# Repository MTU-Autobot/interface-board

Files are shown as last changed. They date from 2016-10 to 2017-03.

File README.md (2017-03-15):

# interface-board


Interface board for MTU's IGVC robot. The board connects to an RC controller, wheel encoders, motor controllers, and status lights and is controlled over USB. The microcontroller is a MK20DX256 running a Teensy 3.2 bootloader for easy programming. Main power conversion is handled by a TPS62143 buck converter and can handle up to 17 volts in for compatibility with 12 volt systems.

To interface with the board you need to setup the udev rules found [here](https://www.pjrc.com/teensy/loader_linux.html)

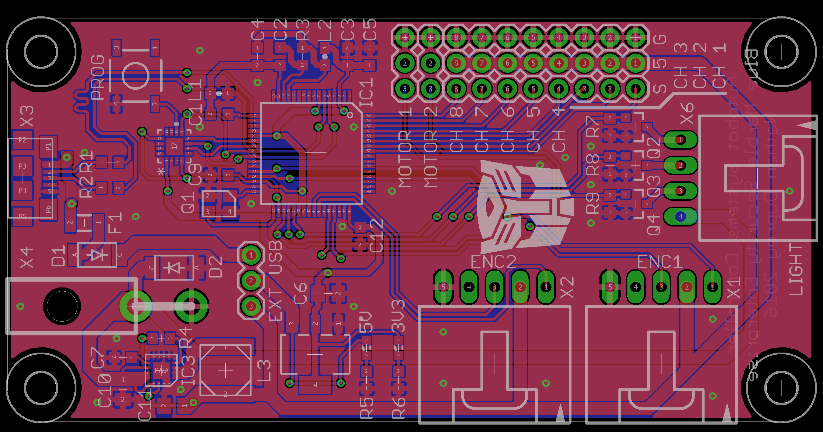
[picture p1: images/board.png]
pcb layout

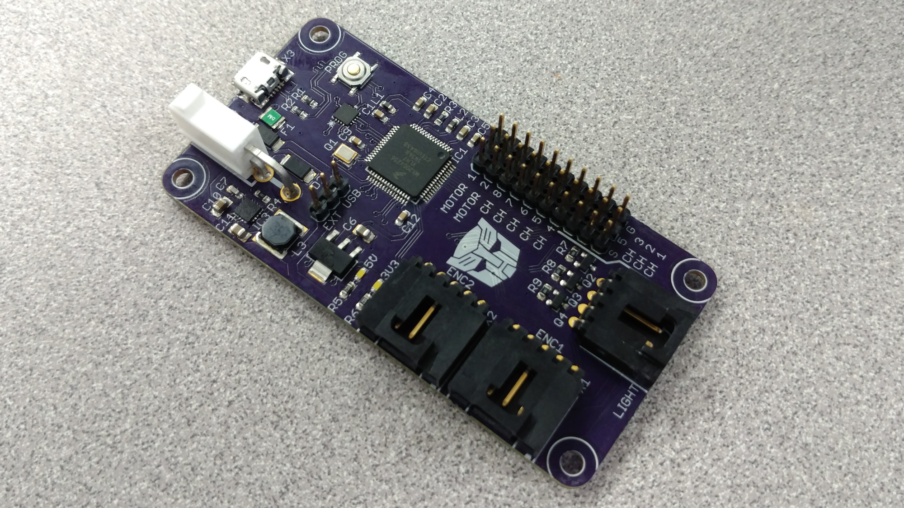
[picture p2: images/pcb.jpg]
assembled board


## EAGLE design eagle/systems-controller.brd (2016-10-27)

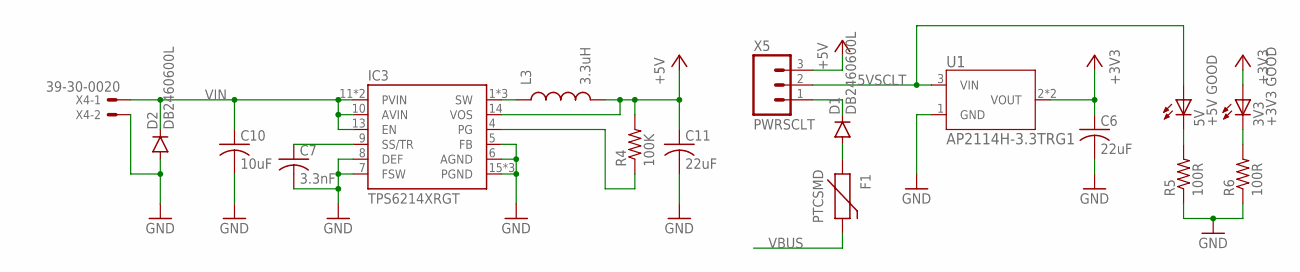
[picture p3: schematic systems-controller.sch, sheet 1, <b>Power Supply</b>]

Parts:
3V3: +3V3 GOOD; SML0603
5V: +5V GOOD; SML0603
C6, C11: 22uF; C0805K
C7: 3.3nF; C0603K
C10: 10uF; C0805K
D1, D2: DB2460600L; SOD-128
F1: PTCSMD; PTC-1206
IC3: TPS6214XRGT; 16-VQFN
L3: 3.3uH; SRN5020
R4: 100K; R0603
R5, R6: 100R; R0603
U1: AP2114H-3.3TRG1; SOT-223
X4: 39-30-0020
X5: PWRSCLT; 1X03

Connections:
5VSCLT: 5V.A, U1.3 (VIN), X5.2
+3V3: 3V3.A, C6.1, U1.2 (VOUT), U1.4 (VOUT); also elsewhere on the board
+5V: C11.1, IC3.14 (VOS), L3.2, R4.2, X5.3; also elsewhere on the board
GND: C6.2, C7.2, C10.2, C11.2, D2.A, IC3.5 (FB), IC3.6 (AGND), IC3.7 (FSW), IC3.8 (DEF), IC3.15 (PGND), IC3.16 (PGND), IC3.PAD (PGND), R5.1, R6.1, U1.1 (GND), X4.2; also elsewhere on the board
unnamed: IC3.4 (PG), R4.1
unnamed: C7.1, IC3.9 (SS/TR)
unnamed: D1.C, X5.1
unnamed: IC3.1 (SW), IC3.2 (SW), IC3.3 (SW), L3.1
unnamed: D1.A, F1.1
unnamed: 5V.C, R5.2
unnamed: 3V3.C, R6.2
VBUS: F1.2; also elsewhere on the board
VIN: C10.1, D2.C, IC3.10 (AVIN), IC3.11 (PVIN), IC3.12 (PVIN), IC3.13 (EN), X4.1; also elsewhere on the board

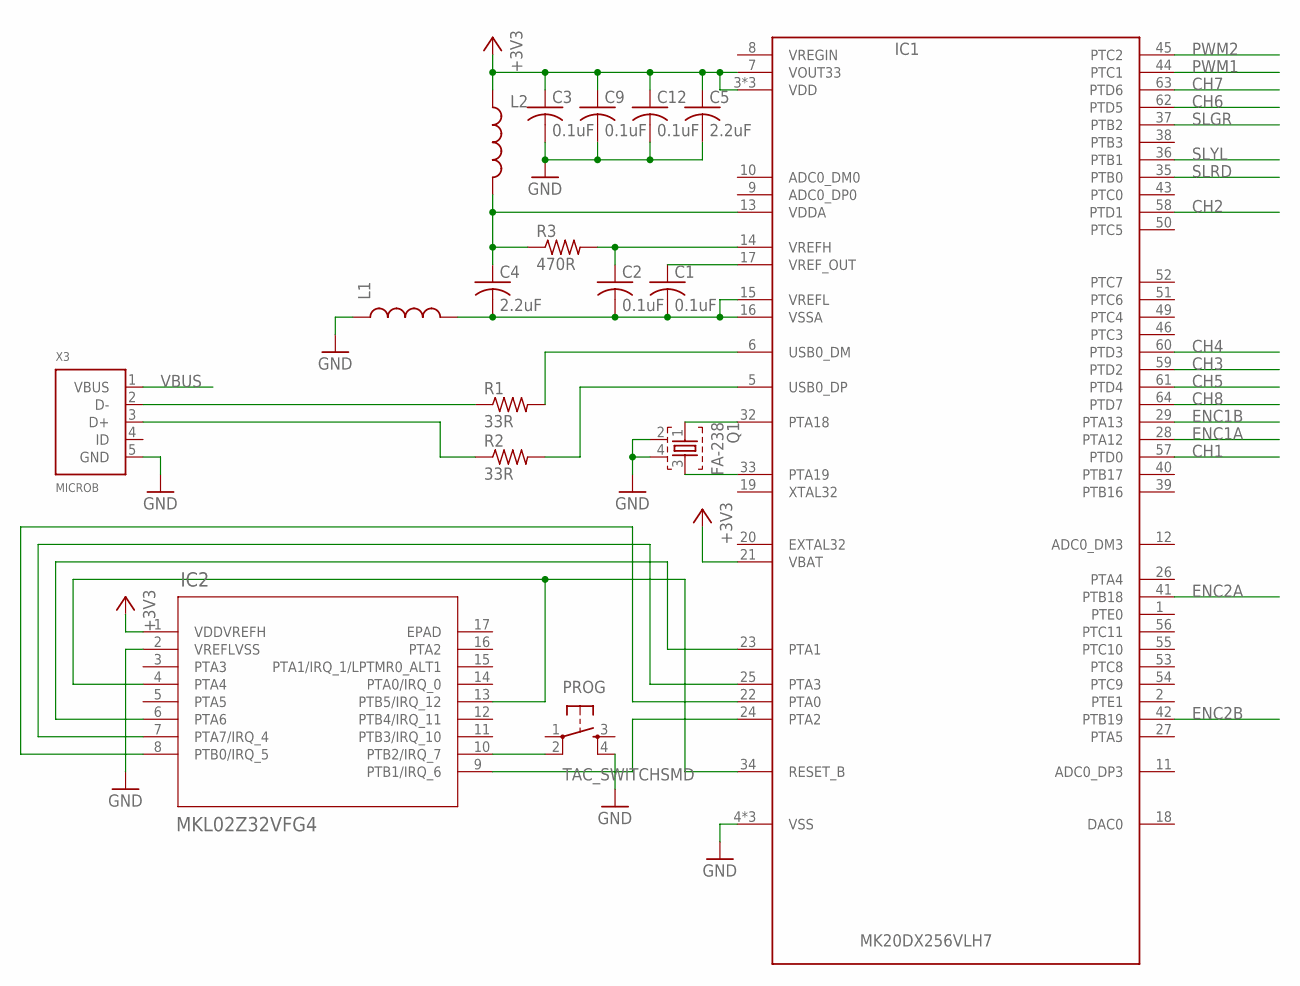
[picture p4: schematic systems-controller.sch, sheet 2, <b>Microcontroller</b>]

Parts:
C1, C2, C3, C9, C12: 0.1uF; C0603K
C4, C5: 2.2uF; C0603K
IC1: MK20DX256VLH7
IC2: MKL02Z32VFG4; QFN-16_3X3X0.65
L1, L2: INDUCTOR30OHM,1.8A; 0603
PROG: TAC_SWITCHSMD; TACTILE-SWITCH-SMD
Q1: FA-238
R1, R2: 33R; R0603
R3: 470R; R0603
X3: MICROB; 10118192

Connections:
+3V3: C3.1, C5.1, C9.1, C12.1, IC1.3 (VDD), IC1.7 (VOUT33), IC1.21 (VBAT), IC1.30 (VDD), IC1.48 (VDD), IC2.1 (VDDVREFH), L2.1; also elsewhere on the board
CH1: IC1.57 (PTD0); also elsewhere on the board
CH2: IC1.58 (PTD1); also elsewhere on the board
CH3: IC1.59 (PTD2); also elsewhere on the board
CH4: IC1.60 (PTD3); also elsewhere on the board
CH5: IC1.61 (PTD4); also elsewhere on the board
CH6: IC1.62 (PTD5); also elsewhere on the board
CH7: IC1.63 (PTD6); also elsewhere on the board
CH8: IC1.64 (PTD7); also elsewhere on the board
ENC1A: IC1.28 (PTA12); also elsewhere on the board
ENC1B: IC1.29 (PTA13); also elsewhere on the board
ENC2A: IC1.41 (PTB18); also elsewhere on the board
ENC2B: IC1.42 (PTB19); also elsewhere on the board
GND: C3.2, C5.2, C9.2, C12.2, IC1.4 (VSS), IC1.31 (VSS), IC1.47 (VSS), IC2.2 (VREFLVSS), L1.1, PROG.4, Q1.2, Q1.4, X3.5 (GND); also elsewhere on the board
unnamed: IC1.25 (PTA3), IC2.7 (PTA7/IRQ_4)
unnamed: IC1.22 (PTA0), IC2.8 (PTB0/IRQ_5)
unnamed: IC1.24 (PTA2), IC2.9 (PTB1/IRQ_6)
unnamed: IC1.23 (PTA1), IC2.6 (PTA6)
unnamed: IC1.34 (RESET_B), IC2.4 (PTA4), IC2.13 (PTB5/IRQ_12)
unnamed: R1.1, X3.2 (D-)
unnamed: IC1.6 (USB0_DM), R1.2
unnamed: R2.1, X3.3 (D+)
unnamed: IC1.5 (USB0_DP), R2.2
unnamed: IC1.32 (PTA18), Q1.1
unnamed: IC1.33 (PTA19), Q1.3
unnamed: C1.2, C2.2, C4.2, IC1.15 (VREFL), IC1.16 (VSSA), L1.2
unnamed: C1.1, IC1.17 (VREF_OUT)
unnamed: C2.1, IC1.14 (VREFH), R3.2
unnamed: C4.1, IC1.13 (VDDA), L2.2, R3.1
unnamed: IC2.10 (PTB2/IRQ_7), PROG.2
PWM1: IC1.44 (PTC1); also elsewhere on the board
PWM2: IC1.45 (PTC2); also elsewhere on the board
SLGR: IC1.37 (PTB2); also elsewhere on the board
SLRD: IC1.35 (PTB0); also elsewhere on the board
SLYL: IC1.36 (PTB1); also elsewhere on the board
VBUS: X3.1 (VBUS); also elsewhere on the board

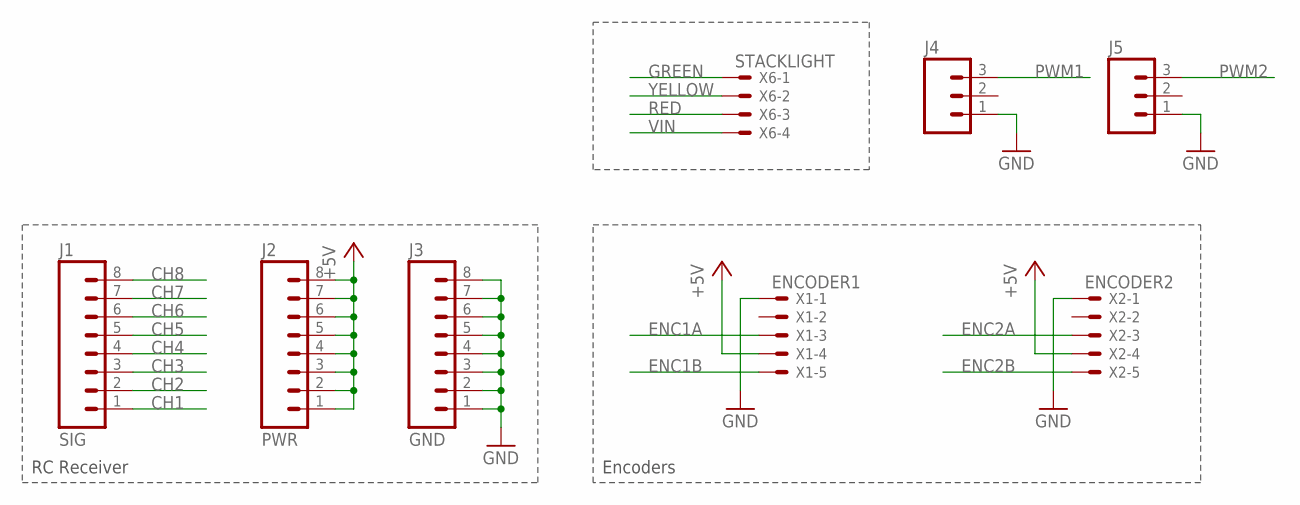
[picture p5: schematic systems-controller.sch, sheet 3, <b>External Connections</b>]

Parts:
J1: SIG; 1X08_ROUND
J2: PWR; 1X08_ROUND
J3: GND; 1X08_ROUND
J4, J5: M03PTH; 1X03
X1: ENCODER1; 70553-05
X2: ENCODER2; 70553-05
X6: STACKLIGHT; 70553-04

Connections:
+5V: J2.1, J2.2, J2.3, J2.4, J2.5, J2.6, J2.7, J2.8, X1.4, X2.4; also elsewhere on the board
CH1: J1.1; also elsewhere on the board
CH2: J1.2; also elsewhere on the board
CH3: J1.3; also elsewhere on the board
CH4: J1.4; also elsewhere on the board
CH5: J1.5; also elsewhere on the board
CH6: J1.6; also elsewhere on the board
CH7: J1.7; also elsewhere on the board
CH8: J1.8; also elsewhere on the board
ENC1A: X1.3; also elsewhere on the board
ENC1B: X1.5; also elsewhere on the board
ENC2A: X2.3; also elsewhere on the board
ENC2B: X2.5; also elsewhere on the board
GND: J3.1, J3.2, J3.3, J3.4, J3.5, J3.6, J3.7, J3.8, J4.1, J5.1, X1.1, X2.1; also elsewhere on the board
GREEN: X6.1; also elsewhere on the board
PWM1: J4.3; also elsewhere on the board
PWM2: J5.3; also elsewhere on the board
RED: X6.3; also elsewhere on the board
VIN: X6.4; also elsewhere on the board
YELLOW: X6.2; also elsewhere on the board

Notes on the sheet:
RC Receiver
Encoders

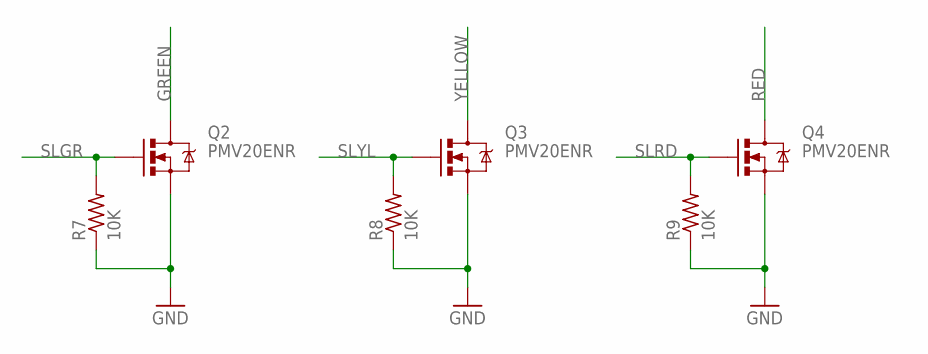
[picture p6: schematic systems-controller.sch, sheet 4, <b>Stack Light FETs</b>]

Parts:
Q2, Q3, Q4: PMV20ENR; SOT23-3
R7, R8, R9: 10K; R0603

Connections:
GND: Q2.2 (S), Q3.2 (S), Q4.2 (S), R7.1, R8.1, R9.1; also elsewhere on the board
GREEN: Q2.3 (D); also elsewhere on the board
RED: Q4.3 (D); also elsewhere on the board
SLGR: Q2.1 (G), R7.2; also elsewhere on the board
SLRD: Q4.1 (G), R9.2; also elsewhere on the board
SLYL: Q3.1 (G), R8.2; also elsewhere on the board
YELLOW: Q3.3 (D); also elsewhere on the board

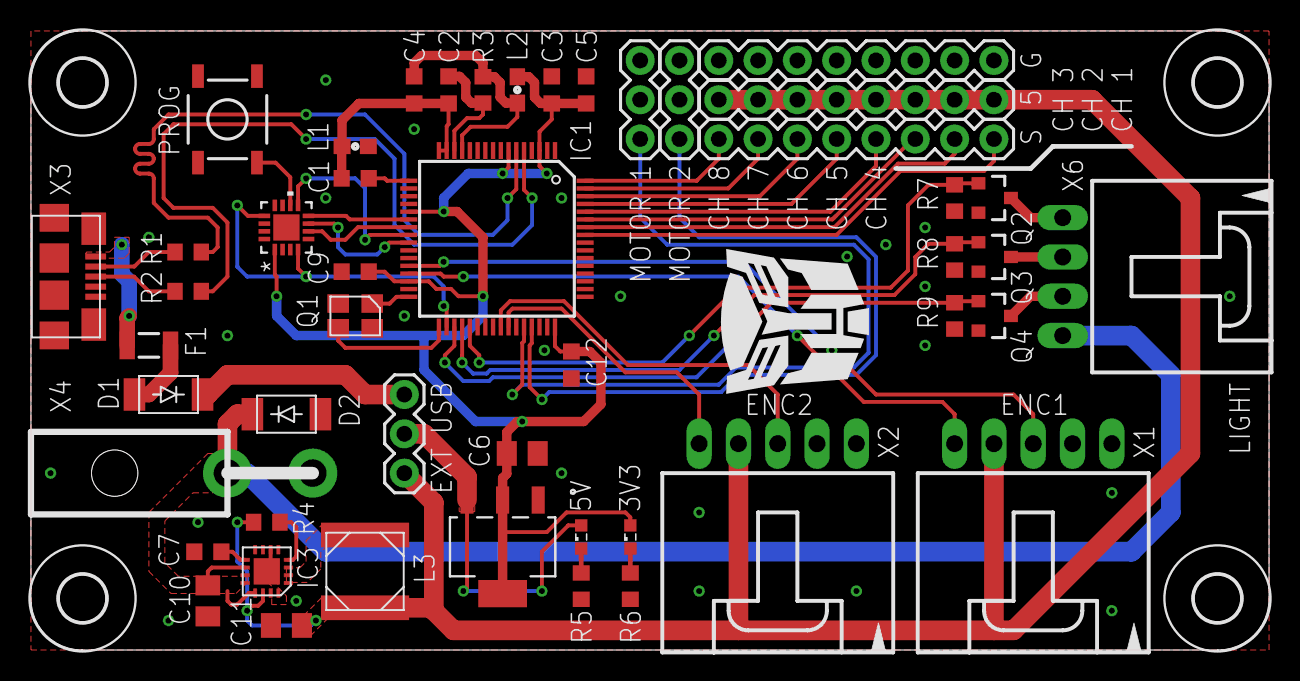
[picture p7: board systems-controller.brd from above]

Board: 2 copper layers, 80.0 x 40.0 mm, 52 parts (0 on the bottom side), 49 nets.

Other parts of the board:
U$1, U$2, U$3, U$4: 3,0

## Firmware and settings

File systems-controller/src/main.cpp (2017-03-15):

#include <stdio.h>
#include <string.h>
#include <math.h>
#include "QuadDecode_def.h"
#include "PID_v1.h"

extern "C" {
    #include "kinetis.h"
    #include "serial.h"
    #include "rc.h"
    #include "pwm.h"
}

// uncomment this to use pid control - doesnt really work yet
//#define USE_PID_CONTROL

// speed calculation stuff
// encoders are 512 counts per revolution, 4 pulses per count. 20:1 gearbox
#define WHEEL_DIAMETER 2 * 0.371475
#define CNTS_PER_REV_WHEEL 512 * 4 * 20
#define CNTS_PER_REV 512 * 4
#define RPM_TO_SPEED (WHEEL_DIAMETER * PI) / 60.0
#define TICKS_TO_DIST (PI * WHEEL_DIAMETER) / CNTS_PER_REV_WHEEL

// stack light pins and mode
#define SL_RED 0x01
#define SL_YELLOW 0x04
#define SL_GREEN 0x02
#define MODE_ESTOP 0
#define MODE_MANUAL 1
#define MODE_AUTO 2

// timekeeping
#define FS_TIME 500000
#define BLINK_TIME 750000
volatile uint32_t micross = 0;

// variables for rc receiver
#define NUM_CHANNELS 4
#define RC_X 0
#define RC_Y 1
#define RC_ESTOP 2
#define RC_MODE 3

volatile uint32_t chRise[NUM_CHANNELS];
volatile uint16_t ch[NUM_CHANNELS];
volatile uint8_t pwGood[NUM_CHANNELS];


// encoder and motor variables
#define PID_KP 2.0
#define PID_KI 1.0
#define PID_KD 0.0

int32_t rightEncPos = 0;
int32_t leftEncPos = 0;
volatile int32_t lastRightEncPos = 0;
volatile int32_t lastLeftEncPos = 0;
volatile int32_t rightEncChange = 0;
volatile int32_t leftEncChange = 0;


// interrupt every 1us
void pit0_isr(void){
    // clear interrupt flag
    PIT_TFLG0 = 0x01;
    micross++;
}


#ifdef USE_PID_CONTROL
// interrupt every 1ms
void pit1_isr(void){
    //clear flag
    PIT_TFLG1 = 0x01;

    // calculate RPM
    // (change in pos) * 1000 ms/s * 60 s/min / conversion factor
    rightEncChange = rightEncPos - lastRightEncPos;
    leftEncChange = leftEncPos - lastLeftEncPos;

    lastRightEncPos = rightEncPos;
    lastLeftEncPos = leftEncPos;
}
#endif


// pin change interrupt for rc controller
void portd_isr(void){
    // determine which pin changed
    if(PORTD_PCR0 & PORT_PCR_ISF){
        // clear the flag
        PORTD_PCR0 |= PORT_PCR_ISF;
        // get pulse width
        if(GPIOD_PDIR & 0x01){
            chRise[RC_X] = micross;
        }else{
            ch[RC_X] = micross - chRise[RC_X];
            pwGood[RC_X] = 1;
        }
    }else if(PORTD_PCR1 & PORT_PCR_ISF){
        // if not PD0, then PD1
        PORTD_PCR1 |= PORT_PCR_ISF;
        // get pulse width
        if(GPIOD_PDIR & 0x02){
            chRise[RC_Y] = micross;
        }else{
            ch[RC_Y] = micross - chRise[RC_Y];
            pwGood[RC_Y] = 1;
        }
    }else if(PORTD_PCR2 & PORT_PCR_ISF){
        PORTD_PCR2 |= PORT_PCR_ISF;
        // get pulse width
        if(GPIOD_PDIR & 0x04){
            chRise[RC_ESTOP] = micross;
        }else{
            ch[RC_ESTOP] = micross - chRise[RC_ESTOP];
            pwGood[RC_ESTOP] = 1;
            //serialPrint("wtf\n");
        }
    }else if(PORTD_PCR3 & PORT_PCR_ISF){
        PORTD_PCR3 |= PORT_PCR_ISF;
        // get pulse width
        if(GPIOD_PDIR & 0x08){
            chRise[RC_MODE] = micross;
        }else{
            ch[RC_MODE] = micross - chRise[RC_MODE];
            pwGood[RC_MODE] = 1;
        }
    }
}


// create two encoder objects
QuadDecode<1> rightEnc;
QuadDecode<2> leftEnc;

#ifdef USE_PID_CONTROL
// create PID objects for each wheel
double leftPidSetpoint, leftPidInput, leftPidOutput = 0.0;
double rightPidSetpoint, rightPidInput, rightPidOutput = 0.0;
PID leftPID(&leftPidInput, &leftPidOutput, &leftPidSetpoint, PID_KP, PID_KI, PID_KD, REVERSE);
PID rightPID(&rightPidInput, &rightPidOutput, &rightPidSetpoint, PID_KP, PID_KI, PID_KD, REVERSE);
#endif

int main(){
    // stack light pin configuration, PORTB 0-2
    PORTB_PCR0 = PORT_PCR_MUX(1) | PORT_PCR_DSE;
    PORTB_PCR1 = PORT_PCR_MUX(1) | PORT_PCR_DSE;
    PORTB_PCR2 = PORT_PCR_MUX(1) | PORT_PCR_DSE;
    GPIOB_PDDR |= (SL_RED | SL_YELLOW | SL_GREEN);

    // enable PIT module and clocking
    SIM_SCGC6 |= SIM_SCGC6_PIT;
    PIT_MCR = 0x00;
    // load 35 for 1us period at 36 MHz?
    PIT_LDVAL0 = 0x23;
    // enable interrupt
    PIT_TCTRL0 = 0x03;
    // 1ms period
    PIT_LDVAL1 = 0x8C9F;
    PIT_TCTRL1 = 0x03;

    // enable PIT interrupts
    NVIC_ENABLE_IRQ(IRQ_PIT_CH0);
    #ifdef USE_PID_CONTROL
    NVIC_ENABLE_IRQ(IRQ_PIT_CH1);
    #endif

    // start pwm and set both outputs to 1.5ms
    pwmInit();
    pwmSetPeriod(PWM1, MID_PERIOD);
    pwmSetPeriod(PWM2, MID_PERIOD);
    rcInit();

    // setup and start encoder objects
    rightEnc.setup();
    leftEnc.setup();
    rightEnc.start();
    leftEnc.start();
    rightEnc.zeroFTM();
    leftEnc.zeroFTM();

    #ifdef USE_PID_CONTROL
    // setup PID
    leftPID.SetMode(AUTOMATIC);
    leftPID.SetOutputLimits(-100, 100);
    rightPID.SetMode(AUTOMATIC);
    rightPID.SetOutputLimits(-100, 100);
    #endif

    char printBuf[128] = "";
    char recvBuf[128] = "";

    // timekeeping
    uint32_t currTime = 0;
    uint32_t prevTime = 0;
    uint32_t endTime = 0;
    uint32_t fsTimer = 0;
    uint32_t blinkTimer = 0;

    // misc mode and channel variables
    uint8_t failsafe = 1;
    uint16_t chLast[NUM_CHANNELS];
    uint8_t mode = MODE_ESTOP;

    // motor variables for manual control
    int16_t ch0Mapped = 0;
    int16_t ch1Mapped = 0;
    int16_t rPl = 0;
    int16_t rMl = 0;
    int16_t rightMotor = 0;
    int16_t leftMotor = 0;

    while(1){
        // get encoder positions and calculate distances
        rightEncPos = -1 * rightEnc.calcPosn();
        leftEncPos = leftEnc.calcPosn();
        currTime = micross;

        // check pulse widths
        for(uint8_t i = 0; i < NUM_CHANNELS; i++){
            if(checkPulse(ch[i])){
                chLast[i] = ch[i];
            }else{
                pwGood[i] = 0;
                ch[i] = chLast[i];
            }
        }

        //failsafe check
        if(micross - fsTimer > FS_TIME){
            fsTimer = micross;

            for(uint8_t i = 0; i < NUM_CHANNELS; i++){
                if(pwGood[i]){
                    failsafe = 0;
                }else{
                    failsafe = 1;
                    mode = MODE_ESTOP;
                    break;
                }
            }

            // clear good flag after check
            for(uint8_t i = 0; i < NUM_CHANNELS; i++){
                pwGood[i] = 0;
            }
        }

        // get operation mode
        if(!failsafe){
            mode = getMode(ch[RC_MODE], ch[RC_ESTOP], MODE_MIN, MODE_MID, MODE_MAX, RC_THRESH);
        }

        if(mode == MODE_ESTOP){
            // stack light to red
            GPIOB_PDOR = SL_RED;

            // kill motors
            pwmSetPeriod(PWM1, MID_PERIOD);
            pwmSetPeriod(PWM2, MID_PERIOD);
        }else if(mode == MODE_MANUAL){
            // stack light to yellow
            GPIOB_PDOR = SL_YELLOW;

            // calculate motor values, single stick to tank drive
            // see http://home.kendra.com/mauser/Joystick.html for an explaination
            ch0Mapped = MID_PERIOD - (int16_t)map(ch[RC_X], CH0_MIN, CH0_MAX, MIN_PERIOD, MAX_PERIOD);
            ch1Mapped = (int16_t)map(ch[RC_Y], CH1_MIN, CH1_MAX, MAX_PERIOD, MIN_PERIOD);
            rPl = (MAX_PERIOD - abs(ch0Mapped)) * (ch1Mapped / MAX_PERIOD) + ch1Mapped;
            rMl = (MAX_PERIOD - ch1Mapped) * (ch0Mapped / MAX_PERIOD) + ch0Mapped;
            rightMotor = bound(rPl + rMl, MIN_PERIOD, MAX_PERIOD);
            leftMotor = bound(rPl - rMl, MIN_PERIOD, MAX_PERIOD);

            #ifndef USE_PID_CONTROL
            // apply speed limits
            rightMotor = map(rightMotor, MIN_PERIOD, MAX_PERIOD, LOW_LIMIT_PERIOD-50, HIGH_LIMIT_PERIOD+50);
            leftMotor = map(leftMotor, MIN_PERIOD, MAX_PERIOD, LOW_LIMIT_PERIOD, HIGH_LIMIT_PERIOD);
            #endif

            #ifdef USE_PID_CONTROL
            // PID computation
            leftPidInput = map(leftEncChange, -52, 52, -100, 100);
            rightPidInput = map(rightEncChange, -52, 52, -100, 100);
            leftPidSetpoint = map(leftMotor, MIN_PERIOD, MAX_PERIOD, 100, -100);
            rightPidSetpoint = map(rightMotor, MIN_PERIOD, MAX_PERIOD, 100, -100);
            leftPID.Compute();
            rightPID.Compute();

            leftMotor = map(leftPidOutput, -100, 100, LOW_LIMIT_PERIOD, HIGH_LIMIT_PERIOD);
            rightMotor = map(rightPidOutput, -100, 100, LOW_LIMIT_PERIOD, HIGH_LIMIT_PERIOD);

            if(currTime - prevTime >= 10000){
                prevTime = currTime;
                sprintf(printBuf, "input: %d\tsetpoint: %d\toutput: %d\n", (int)leftPidInput, (int)leftPidSetpoint, (int)leftMotor);
                //sprintf(printBuf, "left: %d\tright: %d\n", (int)leftEncChange, (int)rightEncChange);
                serialPrint(printBuf);
            }
            #endif

            // update outputs
            if(!failsafe){
                pwmSetPeriod(PWM1, rightMotor);
                pwmSetPeriod(PWM2, leftMotor);
            }else{
                pwmSetPeriod(PWM1, MID_PERIOD);
                pwmSetPeriod(PWM2, MID_PERIOD);
            }
        }else if(mode == MODE_AUTO){
            static uint32_t msgNum = 0;

            // blink green for auto mode
            GPIOB_PCOR = SL_RED | SL_YELLOW;
            if(micross - blinkTimer > BLINK_TIME){
                blinkTimer = micross;
                // toggle output
                GPIOB_PTOR = SL_GREEN;
            }

            // serial messages defined in serial.h
            if(serialRead(recvBuf, 128, '\n')){
                if(atoi(recvBuf) == ENCODER_MSG){
                    // create string with message number, encoder positions, and current time
                    sprintf(printBuf, "%d\t%d\t%d\t%u\n", (int)msgNum++, (int)leftEncPos, (int)rightEncPos, (unsigned int)currTime);
                    serialPrint(printBuf);
                }else if(atoi(recvBuf) == DRIVE_MSG){
                    char driveMsg[128] = "";
                    // read drive data and move it to a new string for operating on
                    while(!serialRead(recvBuf, 128, '\n'));
                    strcpy(driveMsg, recvBuf);

                    // split string and store drive commands in array
                    static uint16_t wheelVels[] = {2047, 2047};
                    char * token;
                    token = strtok(driveMsg, "\t");
                    wheelVels[0] = atoi(token);
                    token = strtok(NULL, "\t");
                    wheelVels[1] = atoi(token);

                    // get motor speeds and update outputs
                    leftMotor = map(wheelVels[0], 4095, 0, LOW_LIMIT_PERIOD, HIGH_LIMIT_PERIOD);
                    rightMotor = map(wheelVels[1], 4095, 0, LOW_LIMIT_PERIOD, HIGH_LIMIT_PERIOD);

                    if(!failsafe){
                        pwmSetPeriod(PWM1, rightMotor);
                        pwmSetPeriod(PWM2, leftMotor);
                    }else{
                        pwmSetPeriod(PWM1, MID_PERIOD);
                        pwmSetPeriod(PWM2, MID_PERIOD);
                    }
                }
            }
        }else{
            // also estop mode so kill everything, hopefully without fire 🔥
            GPIOB_PDOR = SL_RED;

            pwmSetPeriod(PWM1, MID_PERIOD);
            pwmSetPeriod(PWM2, MID_PERIOD);
        }
    }
}

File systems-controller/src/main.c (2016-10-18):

#include <stdio.h>
#include <string.h>
#include "kinetis.h"
#include "serial.h"
#include "rc.h"
#include "pwm.h"

volatile uint32_t micross = 0;

volatile uint32_t ch1rise = 0;
volatile uint32_t ch1pw = 0;
volatile uint32_t ch2rise = 0;
volatile uint32_t ch2pw = 0;
volatile uint32_t ch3rise = 0;
volatile uint32_t ch3pw = 0;
volatile uint32_t ch4rise = 0;
volatile uint32_t ch4pw = 0;

void pit0_isr(void){
    // clear interrupt flag
    PIT_TFLG0 = 0x01;
    micross++;
}

void ftm1_isr(void){
    //
}

// pin change interrupt for rc controller
void portd_isr(void){
    // determine which pin changed
    if(PORTD_PCR0 & PORT_PCR_ISF){
        // clear the flag
        PORTD_PCR0 |= PORT_PCR_ISF;
        // get pulse width
        if(GPIOD_PDIR & 0x01){
            ch1rise = micross;
        }else{
            ch1pw = micross - ch1rise;
        }
    }else if(PORTD_PCR1 & PORT_PCR_ISF){
        // if not PD0, then PD1
        PORTD_PCR1 |= PORT_PCR_ISF;
        // get pulse width
        if(GPIOD_PDIR & 0x02){
            ch2rise = micross;
        }else{
            ch2pw = micross - ch2rise;
        }
    }else if(PORTD_PCR2 & PORT_PCR_ISF){
        PORTD_PCR2 |= PORT_PCR_ISF;
        // get pulse width
        if(GPIOD_PDIR & 0x04){
            ch3rise = micross;
        }else{
            ch3pw = micross - ch3rise;
        }
    }else if(PORTD_PCR3 & PORT_PCR_ISF){
        PORTD_PCR3 |= PORT_PCR_ISF;
        // get pulse width
        if(GPIOD_PDIR & 0x08){
            ch4rise = micross;
        }else{
            ch4pw = micross - ch4rise;
        }
    }
}


int main(){
    // PORTC_PCR5 0xxx x001 x100 x000
    // Pin Mux Control (10-8)=0x001, Drive Strength Enable (6)=1
    PORTC_PCR5 = PORT_PCR_MUX(1) | PORT_PCR_DSE;
    GPIOC_PDDR |= 0x20;
    GPIOC_PDOR |= 0x20;

    // encoder pin setup
    PORTA_PCR12 = PORT_PCR_MUX(7) | PORT_PCR_PFE | PORT_PCR_PE;
    PORTA_PCR13 = PORT_PCR_MUX(7) | PORT_PCR_PFE | PORT_PCR_PE;

    // enable PIT module and clocking
    SIM_SCGC6 |= SIM_SCGC6_PIT;
    PIT_MCR = 0x00;
    // load 35 for 1us period at 36 MHz?
    PIT_LDVAL0 = 0x23;
    // enable interrupt
    PIT_TCTRL0 = 0x03;

    // FTM setup
    FTM1_MODE = FTM_MODE_WPDIS;
    FTM1_MODE = FTM_MODE_WPDIS | FTM_MODE_FTMEN;
    // zero out registers just in case
    FTM1_CNT = 0;
    FTM1_MOD = 0;
    FTM1_C0SC = 0;
    FTM1_C1SC = 0;
    FTM1_SC = 0;
    // set registers for filter
    FTM1_FILTER = FTM_FILTER_CH1FVAL(2) | FTM_FILTER_CH0FVAL(2);
    FTM1_CNTIN = 0;
    FTM1_MOD = 0xFFFF;
    FTM1_CNT = 0;
    // set registers for output compare mode
    FTM1_COMBINE = 0;
    FTM1_C0SC = FTM_CSC_MSA;
    FTM1_C0V = 0x6000;
    // quadrature control
    FTM1_QDCTRL = FTM_QDCTRL_PHAPOL | FTM_QDCTRL_PHBPOL | FTM_QDCTRL_QUADEN;
    FTM1_FMS = FTM_FMS_WPEN;

    // enable PIT and PORT and FTM interrupts
    NVIC_ENABLE_IRQ(IRQ_PIT_CH0);
    NVIC_ENABLE_IRQ(IRQ_PORTD);
    NVIC_ENABLE_IRQ(IRQ_FTM1);

    pwmInit();
    pwmSetPeriod(PWM1, 2250);
    pwmSetPeriod(PWM2, 4500);

    while(1){
    }
}

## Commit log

2016-10-11 moved files hopefully
    [systems-controller.brd, systems-controller.sch]
2016-10-12 added pwm headers
    [systems-controller.brd, systems-controller.sch]
2016-10-12 made silkscreen pretty!
    [systems-controller.brd, systems-controller.sch]
2016-10-12 tweaked silkscreen
    [systems-controller.brd]
2016-10-12 fixed silkscreen and un-tented via
    [systems-controller.brd]
2016-10-16 renamed uart to serial
2016-10-17 pwm setup done maybe
2016-10-19 got encoders working with library, removed extra files
2016-10-22 calculating motor values for manual control, cleaned up some misc things
2016-10-23 some pid stuff, not sure how to implement yet
2016-10-25 fixed reversed usb connector footprint
    [systems-controller.brd, systems-controller.sch]
2016-10-25 autobot logo :)
    [systems-controller.brd]
2016-10-27 moved failsafe to top to probably fix erratic behavior
    [main.cpp]
2016-10-27 fixed reversed encoder connectors
    [systems-controller.brd, systems-controller.sch]
2016-10-29 fixed pwm
2016-11-03 added flush to serial print
2016-11-16 sending encoder data
2016-11-16 moved encoder update
2017-02-18 include pid library
2017-02-19 pid almost there, need to figure out mapping
2017-02-19 pid working i think, needs tuning now
2017-03-15 added preprocessor pid switches
2017-03-15 add board image

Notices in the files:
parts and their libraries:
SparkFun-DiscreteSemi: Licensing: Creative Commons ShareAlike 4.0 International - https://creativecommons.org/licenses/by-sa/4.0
